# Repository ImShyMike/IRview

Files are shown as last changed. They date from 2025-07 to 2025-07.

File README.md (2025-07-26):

# IRview

A tiny thermal camera with a screen. It's powered by an  ESP32-S3-WROOM-1 with 8mb of PSRAM and 8mb of RAM and uses a Melexis far infrared thermal sensor array with a 32x24 resolution that can measure temperatures from -40 to 300°C and has a 55° FOV and uses a PowerBoost 1000 as a BMS that enables it to use a LiPO battery.

The 320x240px screen at the front is used to display the image data, battery and temperature readings and the buttons are used to switch modes. All pin headers are exposed, even when the case is assembled, to help with debugging. It does not include an usb to UART chip so programming must be done using the exposed TX/RX pins with an external programmer.

---

## Why

Thermal cameras are very expensive and have always felt like magic to me so why not try to make my own on a budget (while also finding out that IR sensors are way more expensive than i expected and that AliExpress always saves the day) :D

---

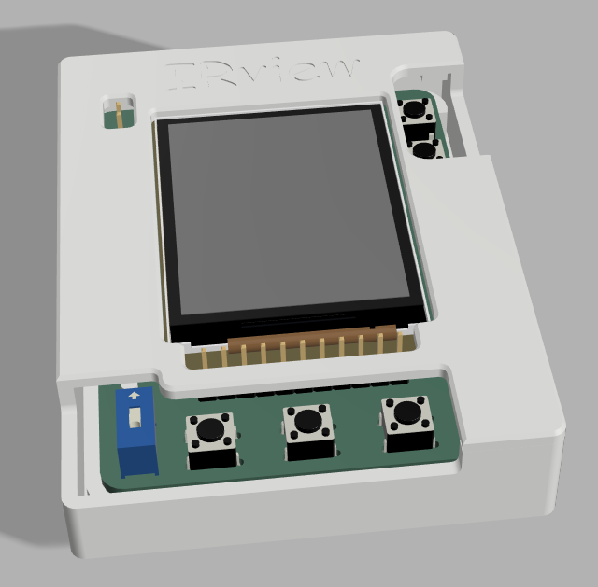
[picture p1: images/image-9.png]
Final Render


---

## PCB

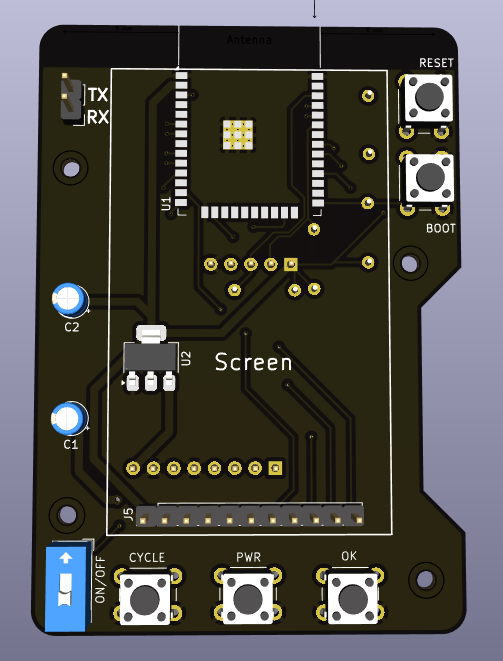
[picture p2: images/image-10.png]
PCB


---

## Schematic

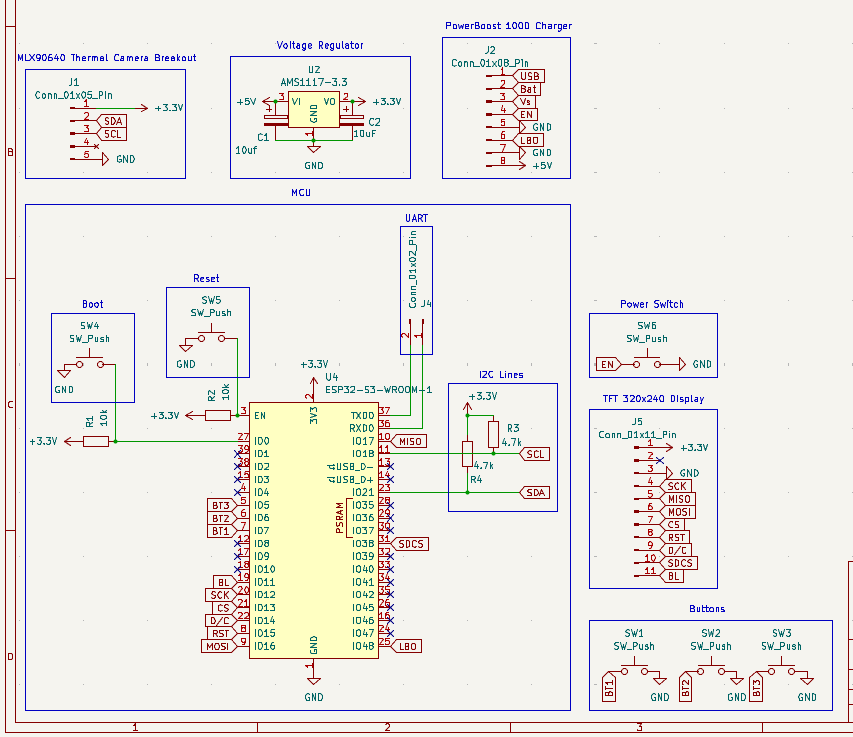
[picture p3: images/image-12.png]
Schematic


---

## BOM

| Part | Qty | Price (USD) | Link |
| --- | :-: | :---: | ---- |
|  MLX90640 |  1  | 26.93 - V | https://www.aliexpress.us/item/1005008180135795.html |
| PowerBoost 1000 Charger |  1  | 12.17 - V | https://www.aliexpress.com/item/1005009316907106.html |
| 2.0" 320x240 Color IPS TFT Display |  1  | 7.40 - (54.77 vendor total) | https://www.adafruit.com/product/4311 |
| ESP32-S3-WROOM-1-N8R8 |  2  | 11.03 - V | https://lcsc.com/product-detail/WiFi-Modules_ESPRESSIF-ESP32-S3-WROOM-1-N8R8_C2913201.html |
| AMS1117-3.3 |  5  | 0.87 - (22.78 vendor total) | https://lcsc.com/product-detail/Voltage-Regulators-Linear-Low-Drop-Out-LDO-Regulators_Advanced-Monolithic-Systems-AMS1117-3-3_C6186.html |
| PCB |  1  | 6.16 | - |
| **Total** | |  **84** | |

(All total vendor prices include shipping and the down arrow represents merged prices in a single order)

(This BOM does not account for the buttons/headers as i already have those)

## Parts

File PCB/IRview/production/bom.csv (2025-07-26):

Designator | Footprint | Quantity | Value | LCSC Part #
J3 | PinSocket_1x09_P2.54mm_Vertical | 1 | Conn_01x09_Socket
U2 | SOT-223-3_TabPin2 | 1 | AMS1117-3.3
U4 | ESP32-S3-WROOM-1 | 1 | ESP32-S3-WROOM-1

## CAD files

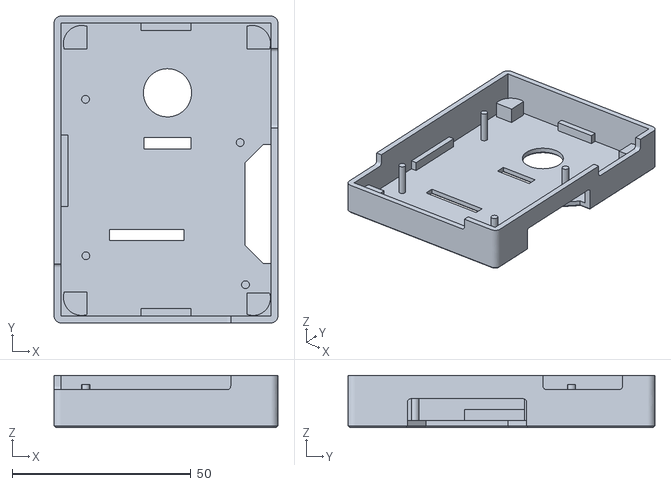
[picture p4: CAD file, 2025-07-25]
CAD/Bottom.stl
62.7 x 85.9 x 14.6

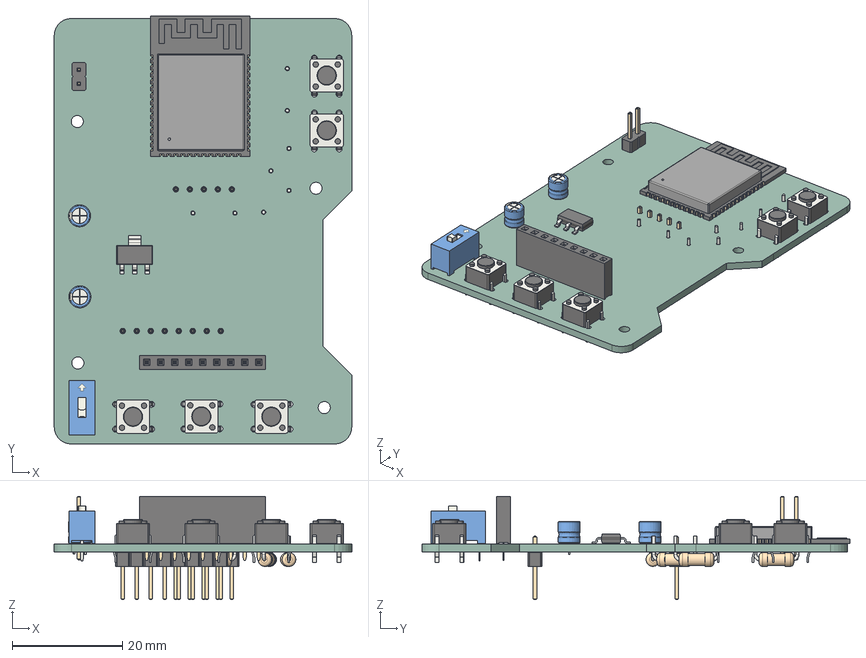
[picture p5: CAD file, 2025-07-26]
PCB/IRview/IRview.step
54.0 x 77.7 x 18.8 mm
SW_DIP_SPSTx01_Slide_9.78x4.72mm_W7.62mm_P2.54mm
ESP32-S3-WROOM-1
CP_Radial_D4.0mm_P2.00mm x 2
SW_PUSH_6mm x 3
SW_PUSH_6mm_H4.3mm x 2
SOT-223
PinHeader_1x02_P2.54mm_Vertical
PinSocket_1x09_P2.54mm_Vertical
R_Axial_DIN0207_L6.3mm_D2.5mm_P7.62mm_Horizontal x 4
PinHeader_1x05_P2.54mm_Vertical
PinHeader_1x08_P2.54mm_Vertical
IRview_PCB

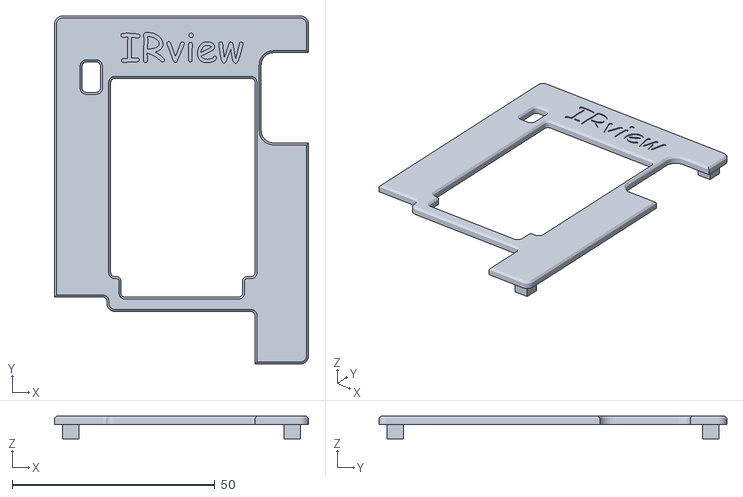
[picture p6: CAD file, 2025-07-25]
CAD/Top.stl
62.7 x 85.9 x 5.60

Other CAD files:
CAD/IRview v6.f3z

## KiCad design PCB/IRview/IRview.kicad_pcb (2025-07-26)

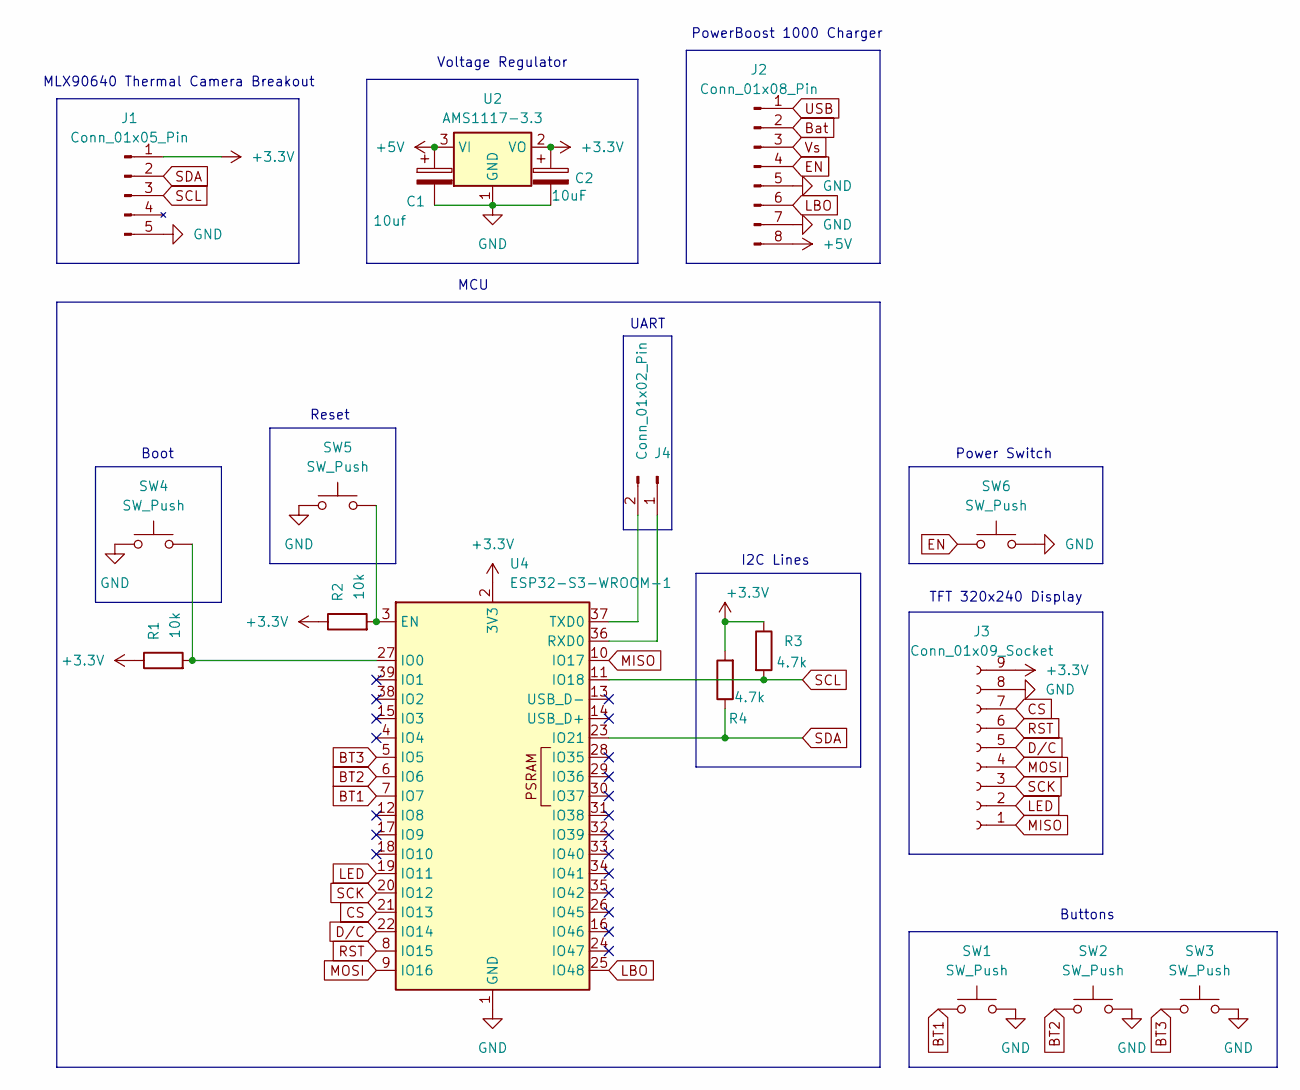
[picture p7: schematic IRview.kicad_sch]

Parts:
C1: 10uf; CP_Radial_D4.0mm_P2.00mm
C2: 10uF; CP_Radial_D4.0mm_P2.00mm
J1: Conn_01x05_Pin; PinHeader_1x05_P2.54mm_Vertical
J2: Conn_01x08_Pin; PinHeader_1x08_P2.54mm_Vertical
J3: Conn_01x09_Socket; PinSocket_1x09_P2.54mm_Vertical
J4: Conn_01x02_Pin; PinHeader_1x02_P2.54mm_Vertical
R1, R2: 10k; R_Axial_DIN0207_L6.3mm_D2.5mm_P7.62mm_Horizontal
R3, R4: 4.7k; R_Axial_DIN0207_L6.3mm_D2.5mm_P7.62mm_Horizontal
SW1, SW2, SW3: SW_Push; SW_PUSH_6mm
SW4, SW5: SW_Push; SW_PUSH_6mm_H4.3mm
SW6: SW_Push; SW_DIP_SPSTx01_Slide_9.78x4.72mm_W7.62mm_P2.54mm
U2: AMS1117-3.3; SOT-223-3_TabPin2
U4: ESP32-S3-WROOM-1

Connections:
+3.3V: C2.1, J1.1 (3-6v), J3.9, R1.1, R2.1, R3.1, R4.2, U2.2 (VO), U4.2 (3V3)
+5V: C1.1, J2.8 (5V), U2.3 (VI)
BT1: SW1.1, U4.7 (IO7)
BT2: SW2.1, U4.6 (IO6)
BT3: SW3.1, U4.5 (IO5)
Bat: J2.2 (Bat)
CS: J3.7, U4.21 (IO13)
D/C: J3.5, U4.22 (IO14)
EN: J2.4 (EN), SW6.1
GND: C1.2, C2.2, J1.5 (GND), J2.5 (GND), J2.7 (G), J3.8, SW1.2, SW2.2, SW3.2, SW4.1, SW5.1, SW6.2, U2.1 (GND), U4.1 (GND), U4.40 (GND), U4.41 (GND)
LBO: J2.6 (LBO), U4.25 (IO48)
LED: J3.2, U4.19 (IO11)
MISO: J3.1, U4.10 (IO17)
MOSI: J3.4, U4.9 (IO16)
unnamed: J4.1, U4.36 (RXD0)
unnamed: J4.2, U4.37 (TXD0)
unnamed: R2.2, SW5.2, U4.3 (EN)
unnamed: R1.2, SW4.2, U4.27 (IO0)
RST: J3.6, U4.8 (IO15)
SCK: J3.3, U4.20 (IO12)
SCL: J1.3 (SCL), R3.2, U4.11 (IO18)
SDA: J1.2 (SDA), R4.1, U4.23 (IO21)
USB: J2.1 (USB)
Vs: J2.3 (Vs)

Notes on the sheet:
Voltage Regulator
Boot
PowerBoost 1000 Charger
UART
TFT 320x240 Display
I2C Lines
Buttons
Reset
MCU
MLX90640 Thermal Camera Breakout
Power Switch

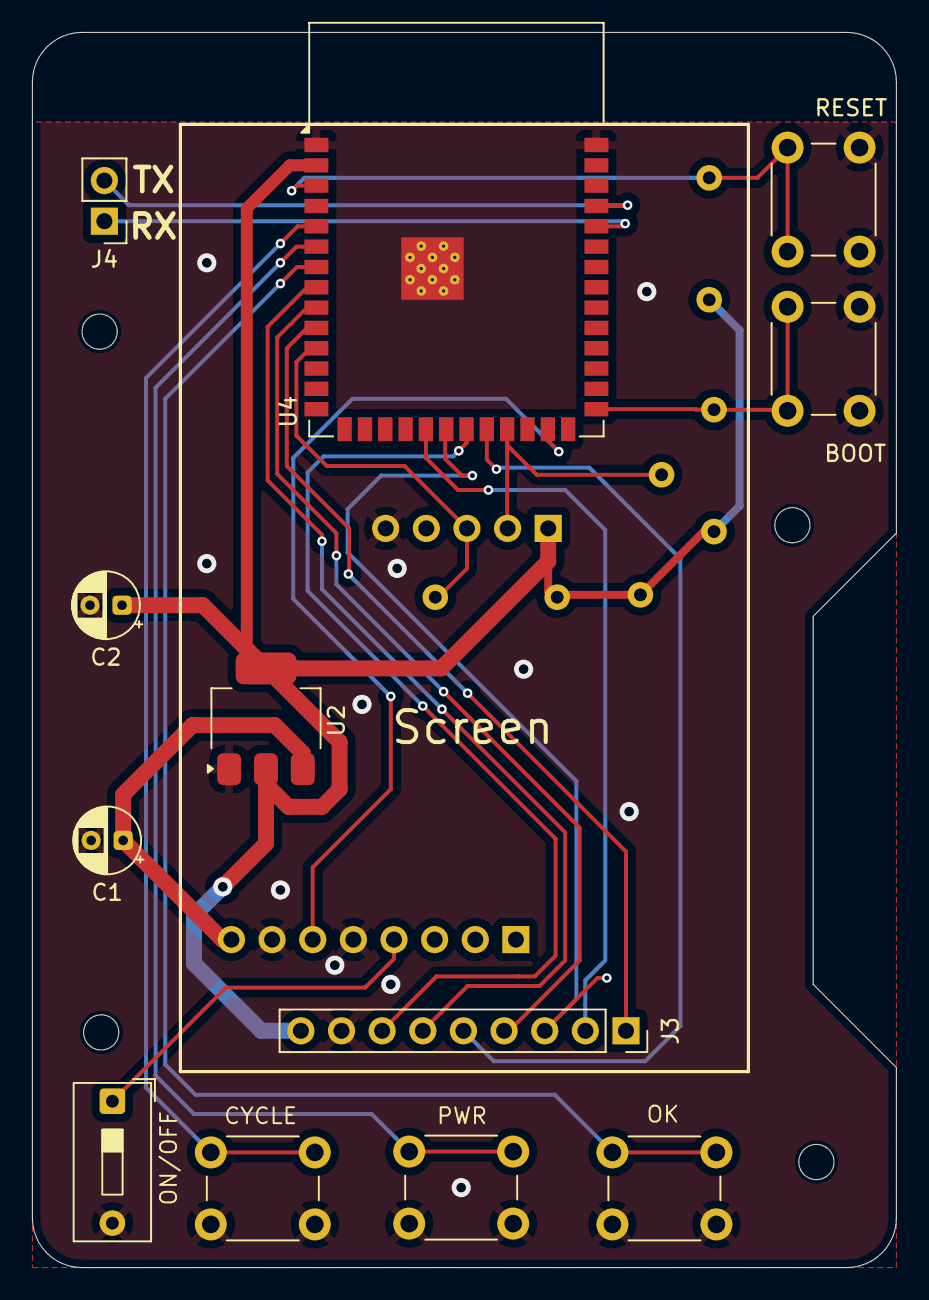
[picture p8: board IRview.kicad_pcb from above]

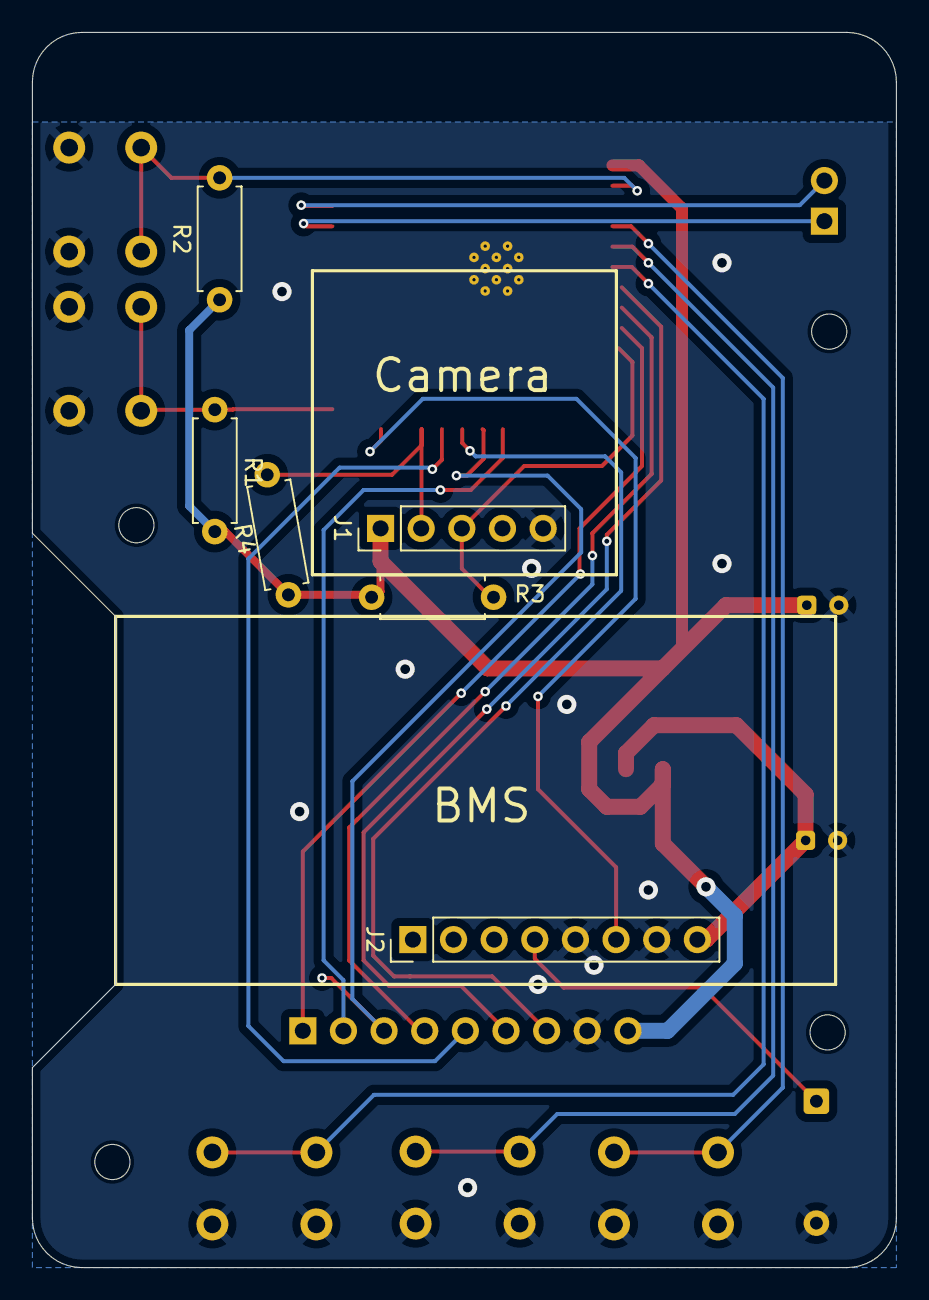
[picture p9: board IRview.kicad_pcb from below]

Board: 2 copper layers, 54.0 x 77.2 mm, 18 parts (6 on the bottom side), 21 nets.

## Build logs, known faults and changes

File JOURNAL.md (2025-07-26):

---
title: "IRview"
author: "ShyMike"
description: "A tiny IR camera with a screen"
created_at: "2025-07-24"
---

## Total time: 21 hours

---

# July 24th: Started researching

Started looking for thermal cameras that fit in the budget and an MCU that could do some simple overlay GUI on the display

Datasheets and stuff:

- $66.50 - [Melexis MLX90640](https://cdn.sparkfun.com/assets/7/b/f/2/d/MLX90640-Datasheet-Melexis.pdf)
- $6.29 - [ESP32-WROOM-32E-N8R2](https://www.espressif.com/sites/default/files/documentation/esp32-wroom-32e_esp32-wroom-32ue_datasheet_en.pdf)
- $19.95 - [PowerBoost 1000 Charger](https://learn.adafruit.com/adafruit-powerboost-1000c-load-share-usb-charge-boost/downloads)
- $19.95 - [2.0" 320x240 Color IPS TFT Display](https://learn.adafruit.com/2-0-inch-320-x-240-color-ips-tft-display/pinouts)

**Total time spent: 4h**

---

# July 24th pt2: Kicad go brrrr

> Copious amounts of rewiring and having to remake the PCB twice because it looked horrible later...

It looks... well... decent :sob:

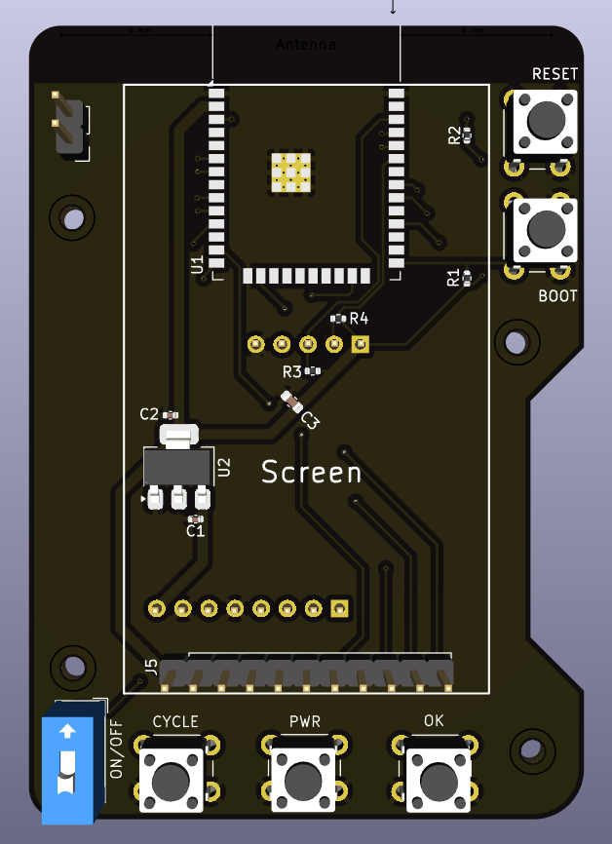
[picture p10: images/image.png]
3d Render


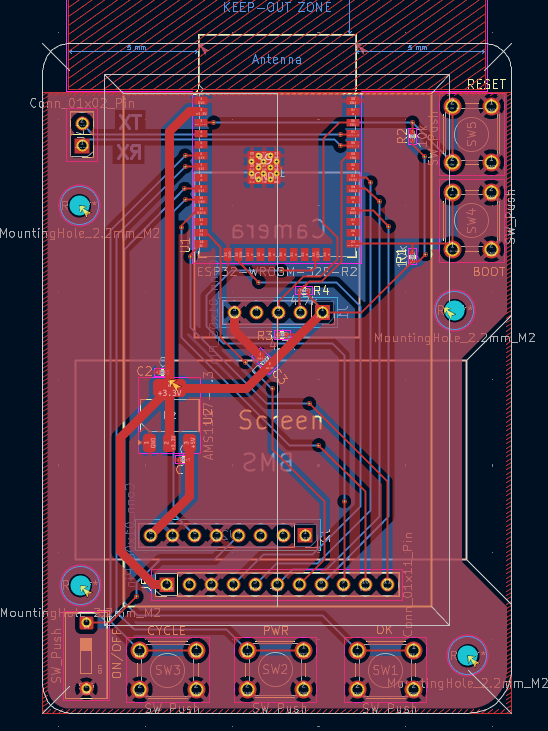
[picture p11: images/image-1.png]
PCB rev2


The vision is there just not sure if it will turn out looking like a melted box :pf:

**Total time spent: 5h**

---

# July 24th pt3: Schematic looks less bad now

Cleaned up the schematic and made it look less like a horrible mess and more like an actual schematic :D

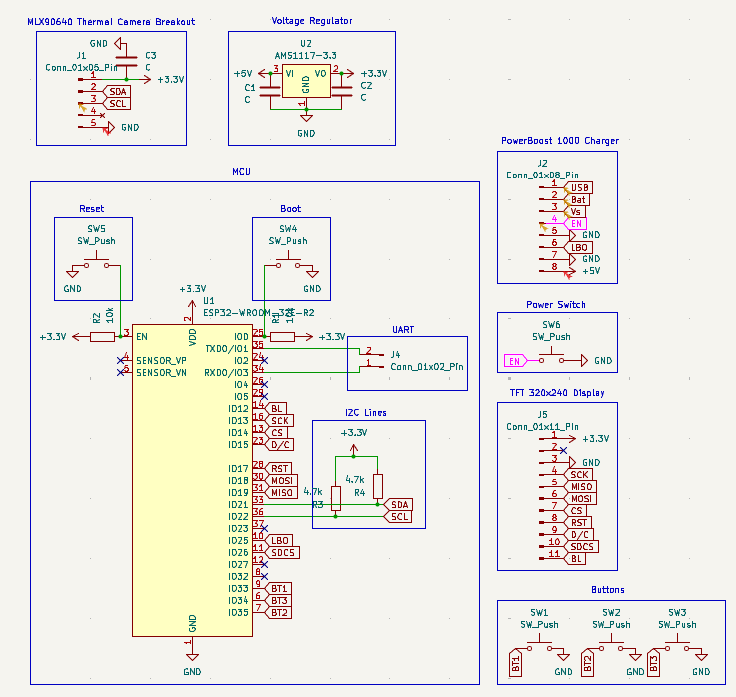
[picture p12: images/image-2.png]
Better schematic


~~i don't even know what rev this is :sob:~~

**Total time spent: 1h**

---

# July 25th: CADDDDDD (i suck at 3D modeling)

> Yes, thats Commic Sans

Made the case and it's now looking less bad :sob:

Has some pins to align the PCB and fix it in place and supports that _should_ make it sturdier

The headers have holes so i can tap into them while the case is assembled, it doesn't look the best but should help with debugging/making the software

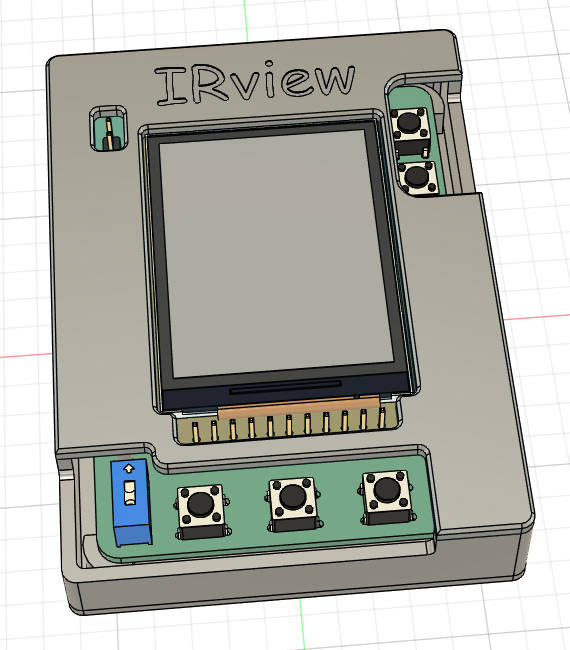
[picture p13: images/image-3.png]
Case CAD with PCB


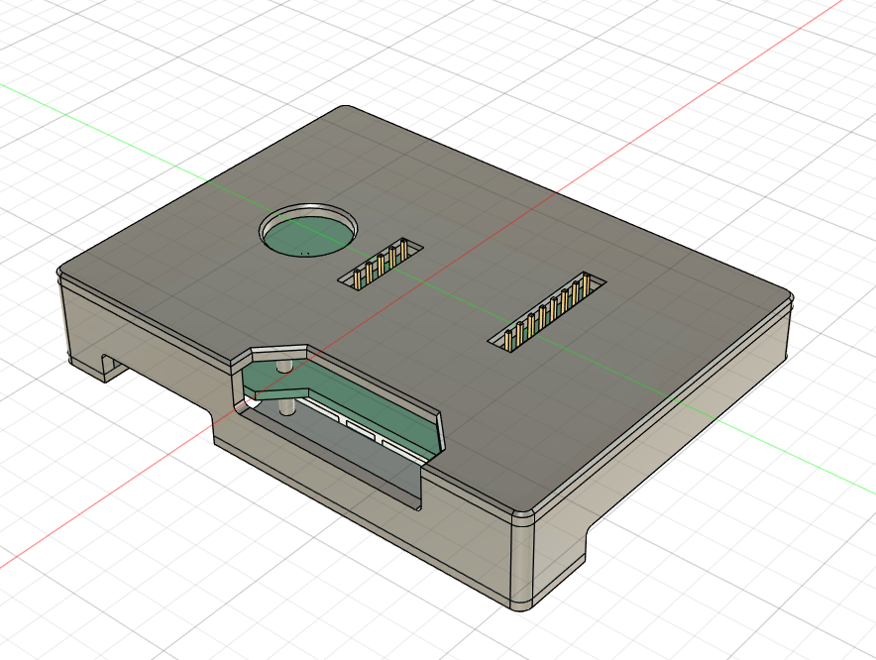
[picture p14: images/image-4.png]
Bottom of the case


Sadly the only model that existed was for the screen so i made the tolerances for the charger and camera less tight so the yactually fit

**Total time spent: 3h**

---

# July 25th p2: My brain isn't working

Remembered that parts don't stick together with magic so i made some adjustments for parts to snap to the correct place

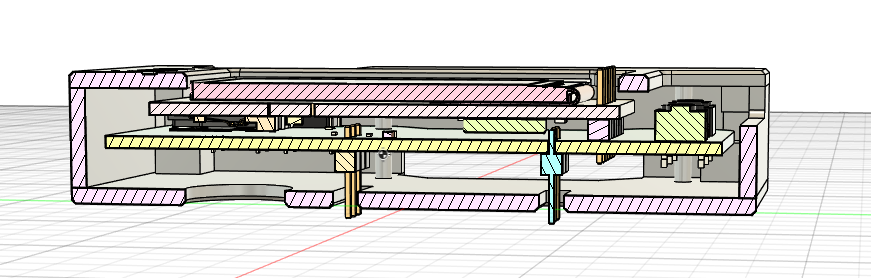
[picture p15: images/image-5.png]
Case slice


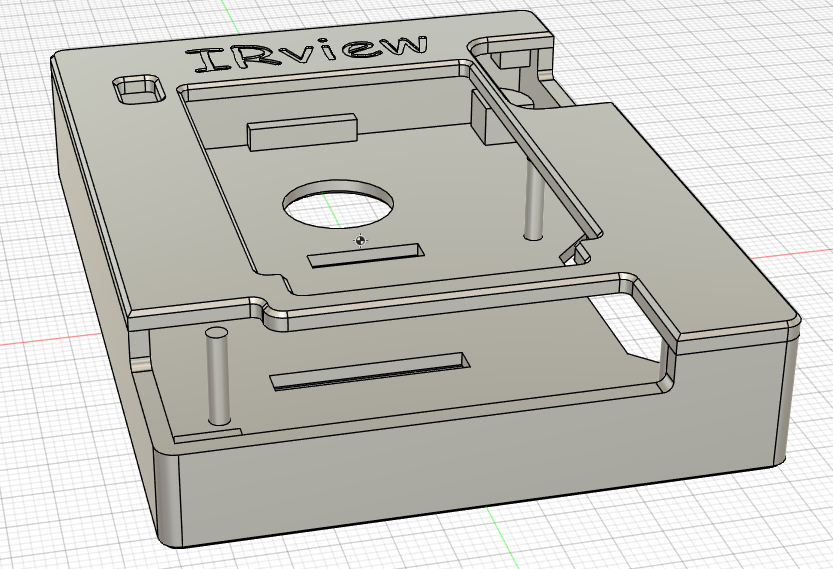
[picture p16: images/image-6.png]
"assembled" case


Also adjusted some tolerances to avoid having to sand stuff down

**Total time spent: 2h**

---

# July 25th p3: BOM stuff

Some more BOM calculations:

- $19.95 - [2.0" 320x240 Color IPS TFT Display](https://www.adafruit.com/product/4311)
- $66.50 - [MLX90640 Thermal Camera Breakout](https://shop.pimoroni.com/products/mlx90640-thermal-camera-breakout?variant=12536948654163)
- $19.95 - [PowerBoost 1000 Charger](https://www.adafruit.com/product/2465)
- $xxxx - PCB

**Total time spent: 1h**

---

# July 25th p4: BOM stuff

Swapped out the resistors and capacitors for THT variants to save on cost and changed some routing

Changed PCB

**Total time spent: 1h**

---

# July 25th p5: Sad times

I was using the wrong ESP32 and the version with PSRAM (what i need) is out of stock everywhere so ill have to swap it out to the S3 which has a completely different footprint AAAAAAAAAAAAAA

Had to do a full rewire D:

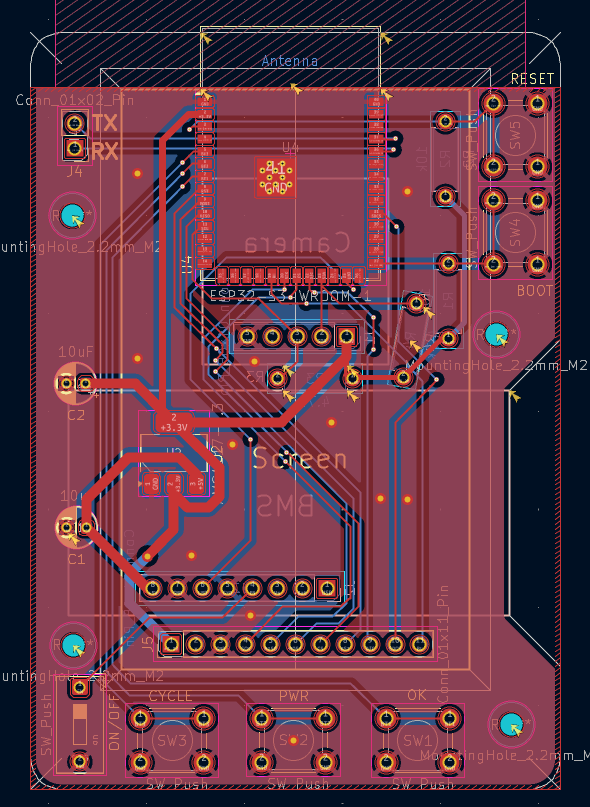
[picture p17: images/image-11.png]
Rewired PCB


Kept everything in the same spot to avoid having to redo the CAD :sob:

**Total time spent: 3h**

---

# July 25th p6: Checking prices

Calculated the prices at checkout and arrived at this:

- $6.16 - PCB
- $17.19 - Components

**Total time spent: 1h**

---

# July 26th: AliExpress maxxing

Changing stuff to AliExpress to save on cost

**Total time spent: 1h**

---

# July 26th pt2: Cheaper display

Had to use a display from AliExpress that has a very different pinout so it required some rewiring

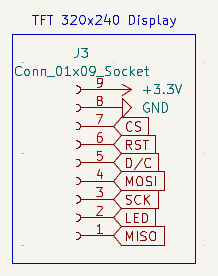
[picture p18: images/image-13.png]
Changed schematic


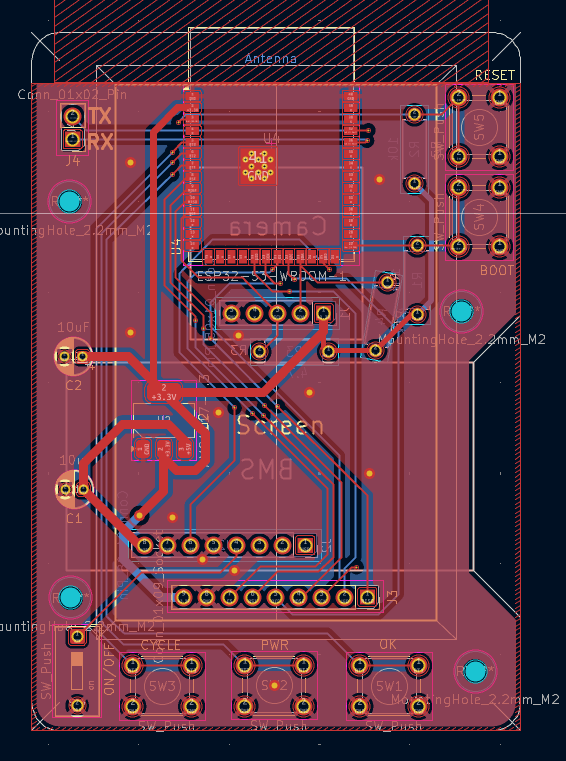
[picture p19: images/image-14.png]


**Total time spent: 1h**

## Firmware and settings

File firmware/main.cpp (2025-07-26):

#include <Wire.h>
#include <SPI.h>
#include <Adafruit_GFX.h> // https://github.com/adafruit/Adafruit-GFX-Library
#include <Adafruit_ST7789.h> // https://github.com/adafruit/Adafruit-ST7735-Library
#include <Adafruit_MLX90640.h> // https://github.com/adafruit/Adafruit_MLX90640

// ==================== PIN DEFINITIONS ====================
// Display pins (SPI)
#define TFT_CS    13
#define TFT_RST   15
#define TFT_DC    14
#define TFT_MOSI  16
#define TFT_SCLK  12

// I2C pins for MLX90640
#define SDA_PIN   21
#define SCL_PIN   18

// Control pins
#define BUTTON_1_PIN 7 // CYCLE
#define BUTTON_2_PIN 6 // PWR
#define BUTTON_3_PIN 5 // OK

// ==================== DISPLAY SETUP ====================
Adafruit_ST7789 tft = Adafruit_ST7789(TFT_CS, TFT_DC, TFT_MOSI, TFT_SCLK, TFT_RST);

// Display dimensions
#define SCREEN_WIDTH  240
#define SCREEN_HEIGHT 320
#define THERMAL_WIDTH 240
#define THERMAL_HEIGHT 180

// ==================== MLX90640 SETUP ====================
Adafruit_MLX90640 mlx;
float frame[32*24];

// ==================== COLOR PALETTES ====================
enum ColorPalette {
  PALETTE_IRON = 0,
  PALETTE_RAINBOW,
  PALETTE_GRAYSCALE,
  PALETTE_HOT,
  PALETTE_JET,
  PALETTE_COUNT
};

ColorPalette currentPalette = PALETTE_IRON;
const char* paletteNames[] = {"Iron", "Rainbow", "Grayscale", "Hot", "Jet"};

// Temperature range for color mapping
float minTemp = 20.0;
float maxTemp = 40.0;

// Hot/cold spot tracking
float hottest = 20.0;
float coldest = 40.0;
int hottestIdx = 0;
int coldestIdx = 0;

// Frame rate control
unsigned long lastFrameTime = 0;
const unsigned long frameInterval = 62; // ~16 FPS (62ms)

// GUI update control
unsigned long lastGUIUpdate = 0;
const unsigned long guiInterval = 200; // 5 FPS (200ms)

// Button debounce
unsigned long lastButtonPress = 0;
bool lastButtonState = HIGH;
const unsigned long debounceDelay = 300;

// ==================== SETUP ====================
void setup() {
  Serial.begin(115200);
  while (!Serial) delay(10);
  Serial.println("IRview Starting...");
  
  // Initialize button
  pinMode(BUTTON_1_PIN, INPUT_PULLUP);
  
  // Initialize I2C
  Wire.begin(SDA_PIN, SCL_PIN);
  Wire.setClock(400000);
  
  // Initialize the display
  tft.init(SCREEN_WIDTH, SCREEN_HEIGHT, SPI_MODE0);
  tft.setRotation(0); // Portrait mode
  tft.fillScreen(ST77XX_BLACK);
  tft.setTextColor(ST77XX_WHITE);
  tft.setTextSize(2);
  
  // Show startup message
  tft.setCursor(20, 50);
  tft.println("IRview");
  tft.setTextSize(1);
  tft.setCursor(20, 80);
  tft.println("Initializing MLX90640...");
  
  // Initialize MLX90640
  if (!mlx.begin(MLX90640_I2CADDR_DEFAULT, &Wire)) {
    Serial.println("MLX90640 not found!");
    tft.setCursor(20, 100);
    tft.setTextColor(ST77XX_RED);
    tft.println("MLX90640 ERROR!");
    while (1) delay(10);
  }
  Serial.println("Found Adafruit MLX90640");
  
  // Set refresh rate
  mlx.setRefreshRate(MLX90640_16_HZ);
  Serial.print("Refresh rate set to: ");
  mlx90640_refreshrate_t rate = mlx.getRefreshRate();
  switch(rate) {
    case MLX90640_0_5_HZ: Serial.println("0.5 Hz"); break;
    case MLX90640_1_HZ: Serial.println("1 Hz"); break;
    case MLX90640_2_HZ: Serial.println("2 Hz"); break;
    case MLX90640_4_HZ: Serial.println("4 Hz"); break;
    case MLX90640_8_HZ: Serial.println("8 Hz"); break;
    case MLX90640_16_HZ: Serial.println("16 Hz"); break;
    case MLX90640_32_HZ: Serial.println("32 Hz"); break;
    case MLX90640_64_HZ: Serial.println("64 Hz"); break;
  }
  
  // Set mode
  mlx.setMode(MLX90640_CHESS);
  
  Serial.println("MLX90640 initialized successfully");
  
  // Clear screen and show ready message
  tft.fillScreen(ST77XX_BLACK);
  tft.setCursor(20, 50);
  tft.setTextColor(ST77XX_GREEN);
  tft.setTextSize(2);
  tft.println("Ready!");
  tft.setTextSize(1);
  tft.setCursor(20, 80);
  tft.setTextColor(ST77XX_CYAN);
  tft.println("Press CYCLE to change palette");
  delay(2000);
}

// ==================== MAIN LOOP ====================
void loop() {
  unsigned long currentTime = millis();
  
  // Handle button input
  handleButton();
  
  // Read thermal data at specified frame rate
  if (currentTime - lastFrameTime >= frameInterval) {
    if (readThermalData()) {
      // Process thermal data in one pass
      processFrame();
      
      // Render interpolated thermal image
      renderThermalImage();
      
      // Update GUI less frequently
      if (currentTime - lastGUIUpdate >= guiInterval) {
        drawUI();
        lastGUIUpdate = currentTime;
      }
      
      lastFrameTime = currentTime;
    }
  }
  
  delay(10);
}

// ==================== INPUT HANDLING ====================
void handleButton() {
  bool buttonState = digitalRead(BUTTON_1_PIN);
  unsigned long currentTime = millis();
  
  if (buttonState == LOW && lastButtonState == HIGH && 
      currentTime - lastButtonPress > debounceDelay) {
    currentPalette = (ColorPalette)((currentPalette + 1) % PALETTE_COUNT);
    lastButtonPress = currentTime;
    Serial.print("Switched to palette: ");
    Serial.println(paletteNames[currentPalette]);
    
    // Show palette change on screen briefly (force immediate GUI update)
    drawUI();
    lastGUIUpdate = currentTime;
  }
  lastButtonState = buttonState;
}

// ==================== MLX90640 FUNCTIONS ====================
bool readThermalData() {
  if (mlx.getFrame(frame) != 0) {
    Serial.println("Failed to read frame data");
    return false;
  }
  return true;
}

void updateTemperatureRange() {
  float tempMin = frame[0];
  float tempMax = frame[0];
  
  // Find min/max temperatures in the frame
  for (int i = 1; i < 768; i++) {
    if (frame[i] < tempMin) tempMin = frame[i];
    if (frame[i] > tempMax) tempMax = frame[i];
  }
  
  // Smooth the range changes to avoid flickering
  minTemp = minTemp * 0.9 + tempMin * 0.1;
  maxTemp = maxTemp * 0.9 + tempMax * 0.1;
  
  // Ensure minimum range for better visualization
  if (maxTemp - minTemp < 2.0) {
    float center = (maxTemp + minTemp) / 2.0;
    minTemp = center - 1.0;
    maxTemp = center + 1.0;
  }
}

// ==================== RENDERING FUNCTIONS ====================
void renderThermalImage() {
  const float scaleX = (float)THERMAL_WIDTH / 32.0;   // 7.5 pixels per thermal pixel
  const float scaleY = (float)THERMAL_HEIGHT / 24.0;  // 7.5 pixels per thermal pixel
  const int offsetY = 40; // Offset for UI space at top
  
  // Render each thermal pixel as a block
  // MLX90640 data: 32 columns × 24 rows
  for (int row = 0; row < 24; row++) {
    for (int col = 0; col < 32; col++) {
      float temperature = frame[row * 32 + col]; // Row-major indexing
      uint16_t color = temperatureToColor(temperature);
      
      // Calculate pixel block dimensions
      int startX = col * scaleX;
      int startY = row * scaleY + offsetY;
      int blockWidth = ((col + 1) * scaleX) - startX;
      int blockHeight = ((row + 1) * scaleY) - startY;
      
      // Fill the pixel block
      tft.fillRect(startX, startY, blockWidth, blockHeight, color);
    }
  }
}

// ==================== MOSTLY "BORROWED" CODE ====================

// Bilinear interpolation function
float bilinearInterpolate(float x, float y) {
  x = constrain(x, 0, 31.999);
  y = constrain(y, 0, 23.999);

  int x1 = (int)x;
  int y1 = (int)y;
  int x2 = min(x1 + 1, 31);
  int y2 = min(y1 + 1, 23);

  float fx = x - x1;
  float fy = y - y1;

  float temp11 = frame[y1 * 32 + x1];
  float temp21 = frame[y1 * 32 + x2];
  float temp12 = frame[y2 * 32 + x1];
  float temp22 = frame[y2 * 32 + x2];

  float temp1 = temp11 * (1 - fx) + temp21 * fx;
  float temp2 = temp12 * (1 - fx) + temp22 * fx;

  return temp1 * (1 - fy) + temp2 * fy;
}

// Render smooth interpolated thermal image
void renderThermalImage() {
  const int offsetY = 40; // Offset for UI space at top
  
  // Render pixel by pixel with interpolation
  for (int screenY = 0; screenY < THERMAL_HEIGHT; screenY++) {
    for (int screenX = 0; screenX < THERMAL_WIDTH; screenX++) {
      float thermalX = (float)screenX * 31.0 / (THERMAL_WIDTH - 1);
      float thermalY = (float)screenY * 23.0 / (THERMAL_HEIGHT - 1);
      
      float temperature = bilinearInterpolate(thermalX, thermalY);
      uint16_t color = temperatureToColor(temperature);
      
      tft.drawPixel(screenX, screenY + offsetY, color);
    }
  }
}

uint16_t temperatureToColor(float temp) {
  float normalized = (temp - minTemp) / (maxTemp - minTemp);
  normalized = constrain(normalized, 0.0, 1.0);
  
  uint8_t r, g, b;
  
  switch (currentPalette) {
    case PALETTE_IRON:
      getIronColor(normalized, &r, &g, &b);
      break;
    case PALETTE_RAINBOW:
      getRainbowColor(normalized, &r, &g, &b);
      break;
    case PALETTE_GRAYSCALE:
      r = g = b = normalized * 255;
      break;
    case PALETTE_HOT:
      getHotColor(normalized, &r, &g, &b);
      break;
    case PALETTE_JET:
      getJetColor(normalized, &r, &g, &b);
      break;
  }
  
  return tft.color565(r, g, b);
}

// ==================== COLOR PALETTE FUNCTIONS ====================
void getIronColor(float value, uint8_t* r, uint8_t* g, uint8_t* b) {
  if (value < 0.25) {
    *r = 0;
    *g = 0;
    *b = value * 4 * 255;
  } else if (value < 0.5) {
    *r = 0;
    *g = (value - 0.25) * 4 * 255;
    *b = 255;
  } else if (value < 0.75) {
    *r = (value - 0.5) * 4 * 255;
    *g = 255;
    *b = 255 - (value - 0.5) * 4 * 255;
  } else {
    *r = 255;
    *g = 255;
    *b = 255 - (value - 0.75) * 4 * 255;
  }
}

void getRainbowColor(float value, uint8_t* r, uint8_t* g, uint8_t* b) {
  float hue = value * 300; // 0 to 300 degrees (blue to red)
  hsvToRgb(hue, 1.0, 1.0, r, g, b);
}

void getHotColor(float value, uint8_t* r, uint8_t* g, uint8_t* b) {
  if (value < 0.33) {
    *r = value * 3 * 255;
    *g = 0;
    *b = 0;
  } else if (value < 0.66) {
    *r = 255;
    *g = (value - 0.33) * 3 * 255;
    *b = 0;
  } else {
    *r = 255;
    *g = 255;
    *b = (value - 0.66) * 3 * 255;
  }
}

void getJetColor(float value, uint8_t* r, uint8_t* g, uint8_t* b) {
  if (value < 0.125) {
    *r = 0;
    *g = 0;
    *b = 128 + value * 8 * 127;
  } else if (value < 0.375) {
    *r = 0;
    *g = (value - 0.125) * 4 * 255;
    *b = 255;
  } else if (value < 0.625) {
    *r = (value - 0.375) * 4 * 255;
    *g = 255;
    *b = 255 - (value - 0.375) * 4 * 255;
  } else if (value < 0.875) {
    *r = 255;
    *g = 255 - (value - 0.625) * 4 * 255;
    *b = 0;
  } else {
    *r = 255 - (value - 0.875) * 8 * 127;
    *g = 0;
    *b = 0;
  }
}

void hsvToRgb(float h, float s, float v, uint8_t* r, uint8_t* g, uint8_t* b) {
  int i = int(h / 60) % 6;
  float f = (h / 60) - i;
  float p = v * (1 - s);
  float q = v * (1 - s * f);
  float t = v * (1 - s * (1 - f));
  
  switch (i) {
    case 0: *r = v * 255; *g = t * 255; *b = p * 255; break;
    case 1: *r = q * 255; *g = v * 255; *b = p * 255; break;
    case 2: *r = p * 255; *g = v * 255; *b = t * 255; break;
    case 3: *r = p * 255; *g = q * 255; *b = v * 255; break;
    case 4: *r = t * 255; *g = p * 255; *b = v * 255; break;
    case 5: *r = v * 255; *g = p * 255; *b = q * 255; break;
  }
}

// ==================== END MOSTLY "BORROWED" CODE ====================

// ==================== UI FUNCTIONS ====================
void drawUI() {
  // Clear top area for UI
  tft.fillRect(0, 0, SCREEN_WIDTH, 40, ST77XX_BLACK);

  tft.setTextColor(ST77XX_WHITE);
  tft.setTextSize(1);
  tft.setCursor(5, 5);
  tft.print("Min: ");
  tft.print(minTemp, 1);
  tft.print("C  Max: ");
  tft.print(maxTemp, 1);
  tft.print("C");

  tft.setCursor(5, 18);
  tft.print("Palette: ");
  tft.print(paletteNames[currentPalette]);
  
  // Clear bottom area for additional info
  const int bottomY = THERMAL_HEIGHT + 40;
  tft.fillRect(0, bottomY, SCREEN_WIDTH, SCREEN_HEIGHT - bottomY, ST77XX_BLACK);

  int centerIndex =  367; // Row 11, Column 15 (center-ish of 32×24 grid)
  float centerTemp = frame[centerIndex];
  
  // Display center temperature
  tft.setTextSize(2);
  tft.setCursor(10, bottomY + 10);
  tft.setTextColor(ST77XX_YELLOW);
  tft.print("Center: ");
  tft.print(centerTemp, 1);
  tft.print("C");
  
  // Display hottest spot
  tft.setTextSize(1);
  tft.setCursor(10, bottomY + 35);
  tft.setTextColor(ST77XX_RED);
  tft.print("Hottest: ");
  tft.print(hottest, 1);
  tft.print("C");
  
  // Display coldest spot
  tft.setCursor(10, bottomY + 50);
  tft.setTextColor(ST77XX_CYAN);
  tft.print("Coldest: ");
  tft.print(coldest, 1);
  tft.print("C");
  
  // Draw crosshair on the thermal image
  int crossX = THERMAL_WIDTH / 2;
  int crossY = THERMAL_HEIGHT / 2 + 40;
  tft.drawFastHLine(crossX - 8, crossY, 16, ST77XX_WHITE);
  tft.drawFastVLine(crossX, crossY - 8, 16, ST77XX_WHITE);
  
  // Draw hottest spot marker (small circle)
  int hotCol = hottestIdx % 32;
  int hotRow = hottestIdx / 32;
  int hotX = hotCol * (THERMAL_WIDTH / 32.0) + (THERMAL_WIDTH / 64.0);
  int hotY = hotRow * (THERMAL_HEIGHT / 24.0) + (THERMAL_HEIGHT / 48.0) + 40;
  tft.drawCircle(hotX, hotY, 3, ST77XX_RED);
  
  // Draw coldest spot marker (small square)
  int coldCol = coldestIdx % 32;
  int coldRow = coldestIdx / 32;
  int coldX = coldCol * (THERMAL_WIDTH / 32.0) + (THERMAL_WIDTH / 64.0);
  int coldY = coldRow * (THERMAL_HEIGHT / 24.0) + (THERMAL_HEIGHT / 48.0) + 40;
  tft.drawRect(coldX - 2, coldY - 2, 4, 4, ST77XX_CYAN);
}

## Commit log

2025-07-24 i forgot to commit the other entry mb gng
    [IRview.kicad_pcb, IRview.kicad_sch]
2025-07-25 cadddddd
    i really need to remember to commit journal changes :sob:
    [IRview.step]
2025-07-25 pcb fixups and changes
    [Bottom.stl, IRview v6.f3z, IRview.kicad_pcb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]
2025-07-25 change esp and rewire
    [IRview.kicad_pcb, IRview.kicad_sch, IRview_preswap.kicad_pcb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]
2025-07-25 bom and stuff
    [BOM.csv, bom.csv, designators.csv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]
2025-07-26 add schematic to README
2025-07-26 change screen
    [BOM.csv, IRview.kicad_pcb, IRview.kicad_sch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]
2025-07-26 add PCB step file
    [IRview.step]
